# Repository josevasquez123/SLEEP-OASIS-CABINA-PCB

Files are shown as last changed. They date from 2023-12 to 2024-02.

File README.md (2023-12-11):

# WNR-CABINA-PCB
Domotic control of LED lights with CAN connection. 

## Topology
imagen
Motherboard has internet connection to receive commands by MQTT and then, send instruction by CAN to the boards inside the rooms. The present board is the one that will be placed inside the room.

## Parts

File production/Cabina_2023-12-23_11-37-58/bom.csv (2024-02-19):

Designator | Footprint | Quantity | Value | LCSC Part #
C102 | C_Elec_10x10.2 | 1 | 330u | C239324
C103 | CP_Elec_10x10.5 | 1 | 220u | C2886113
C104, C105 | 0805 | 2 | 10u | C15850
C300 | 0603 | 1 | 10u | C19702
C301, C302, C303, C304, C308, C311, C312 | 0402 | 7 | 100n | C1525
C305 | 0402 | 1 | 10n | C15195
C306, C307 | 0603 | 2 | 1u | C15849
C309, C310 | 0402 | 2 | 10p | C32949
D100, D201, D205, D209, D212 | SOD_123FL | 5 | SMF24A-TP | C545276
D101 | D_SOD-123 | 1 | MMSZ4697T1G | C48870
D102 | D_SMA | 1 | ss34 | C8678
D103 | 0603 | 1 | GREEN | C72043
D200, D204, D208, D213 | D_SOD-128 | 4 | PROTECCION | C513108
D202, D206, D210, D214 | SOD_123FL | 4 | SM4007PL | C64898
D203 | 0603 | 1 | LED_HEADBOARD | C72038
D207, D211, D215 | 0603 | 3 | LED_TABLE | C72038
H1, H2, H3, H4 | MountingHole_3.2mm_M3 | 4 | MountingHole
J100 | PhoenixContact_MSTBA_2,5_2-G-5,08_1x02_P5.08mm_Horizontal | 1 | VCC INPUT
J101 | JST_B2B-XH-A_LF__SN_ | 1 | SWITCH ON/OFF
J103 | PinHeader_1x02_P2.54mm_Vertical | 1 | FAN VOLTAGE
J200, J201, J202 | PhoenixContact_MSTBA_2,5_5-G-5,08_1x05_P5.08mm_Horizontal | 3 | LIGHT SWITCH & LED STRIP
J203 | PhoenixContact_MSTBA_2,5_2-G-5,08_1x02_P5.08mm_Horizontal | 1 | LED STRIP
J300 | PinSocket_1x03_P2.54mm_Vertical | 1 | Serial Wire Debug
J301 | SW_DIP_SPSTx05_Slide_9.78x14.88mm_W7.62mm_P2.54mm | 1 | CAN_ID_CONFIG
J302 | PhoenixContact_MSTBA_2,5_2-G-5,08_1x02_P5.08mm_Horizontal | 1 | CAN_INPUT
J304 | PinHeader_1x02_P2.54mm_Vertical | 1 | JUMPER_CANL
K200 | Relay_SPDT_Finder_36.11 | 1 | RELAY_HEADBOARD
K201 | Relay_SPDT_Finder_36.11 | 1 | RELAY_TABLE
K202 | Relay_SPDT_Finder_36.11 | 1 | RELAY_CEILING
K203 | Relay_SPDT_Finder_36.11 | 1 | RELAY_SIGN
L101 | SMD_12.3X12.3mm | 1 | 68u | C2929504
L300 | 0603 | 1 | 10n | C913709
Q100 | SOT-23 | 1 | WST4045 | C719073
Q200, Q201, Q202, Q203 | SOT-23 | 4 | MMBT3904 | C20526
R100 | 1206 | 1 | 100K | C17900
R101, R200, R201, R203, R204, R206, R207, R209, R210 | 0603 | 9 | 1k | C21190
R202, R205, R208, R211 | 0603 | 4 | 10K | C25804
R300 | 0402 | 1 | 10k | C25744
R301, R303, R305 | 0805 | 3 | 33k | C17633
R302, R304, R306 | 0805 | 3 | 5.1k | C27834
R308 | 0805 | 1 | 120 | C17437
S300 | SWITCH_SMD | 1 | TS-1187A-B-A-B | C318884
TP100, TP101, TP102, TP103, TP104, TP300, TP301, TP302, TP303, TP304, TP307, TP308 | TestPoint_Pad_D2.0mm | 12 | TestPoint
U100 | TO-263-5_TabPin3 | 1 | LM2596S-5 | C10002
U101 | SOT-223-3_TabPin2 | 1 | AMS1117-3.3 | C6186
U300 | LQFP-48_7x7mm_P0.5mm | 1 | STM32F103C8Tx | C8734
U301 | SOIC-8_3.9x4.9mm_P1.27mm | 1 | MCP2562-E-SN | C191417
Y300 | Crystal_SMD_3225-4Pin_3.2x2.5mm | 1 | 16MHz | C13738

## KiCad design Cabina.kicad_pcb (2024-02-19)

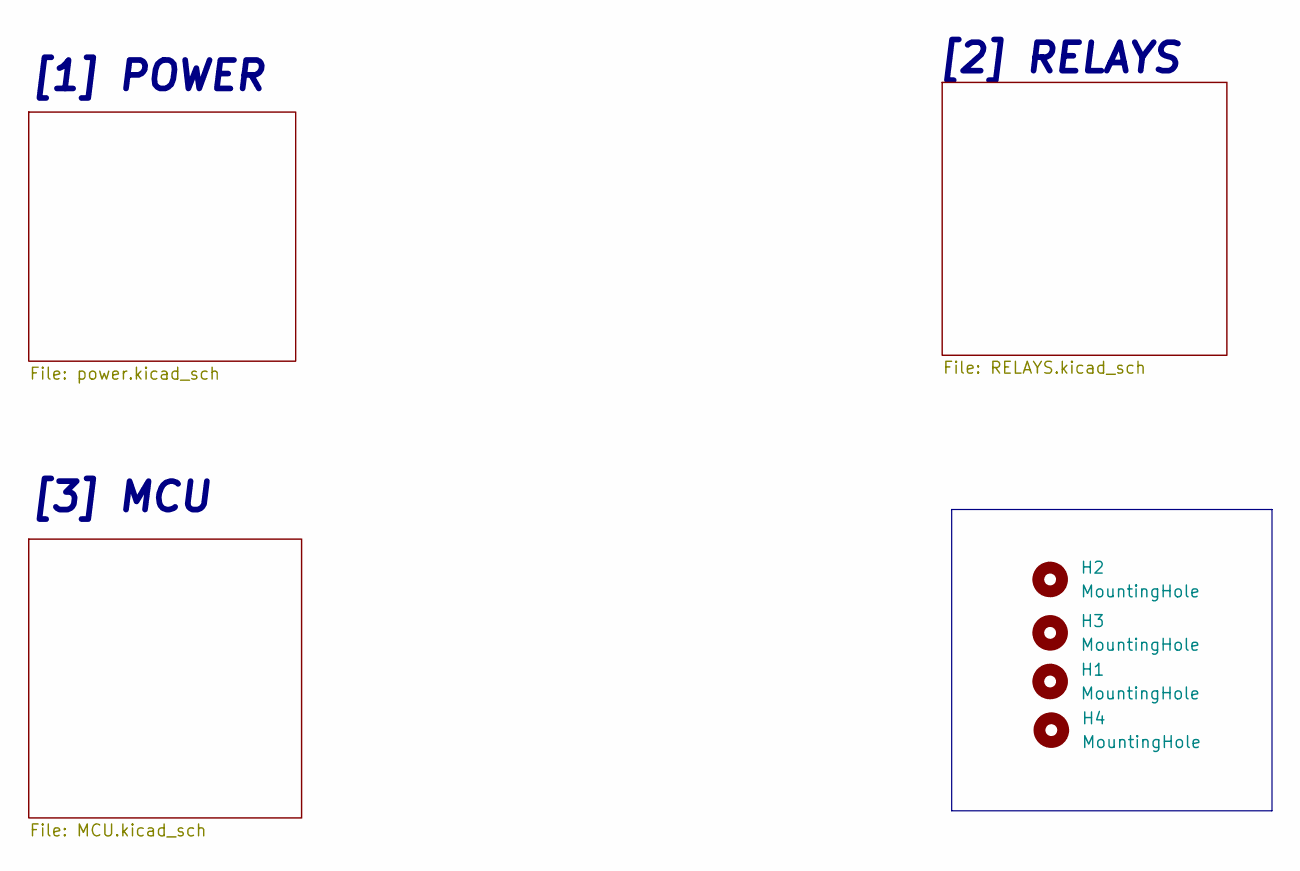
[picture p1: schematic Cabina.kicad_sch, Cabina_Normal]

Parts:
H1, H2, H3, H4: MountingHole; MountingHole_3.2mm_M3

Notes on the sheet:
[1] POWER
[2] RELAYS
[3] MCU

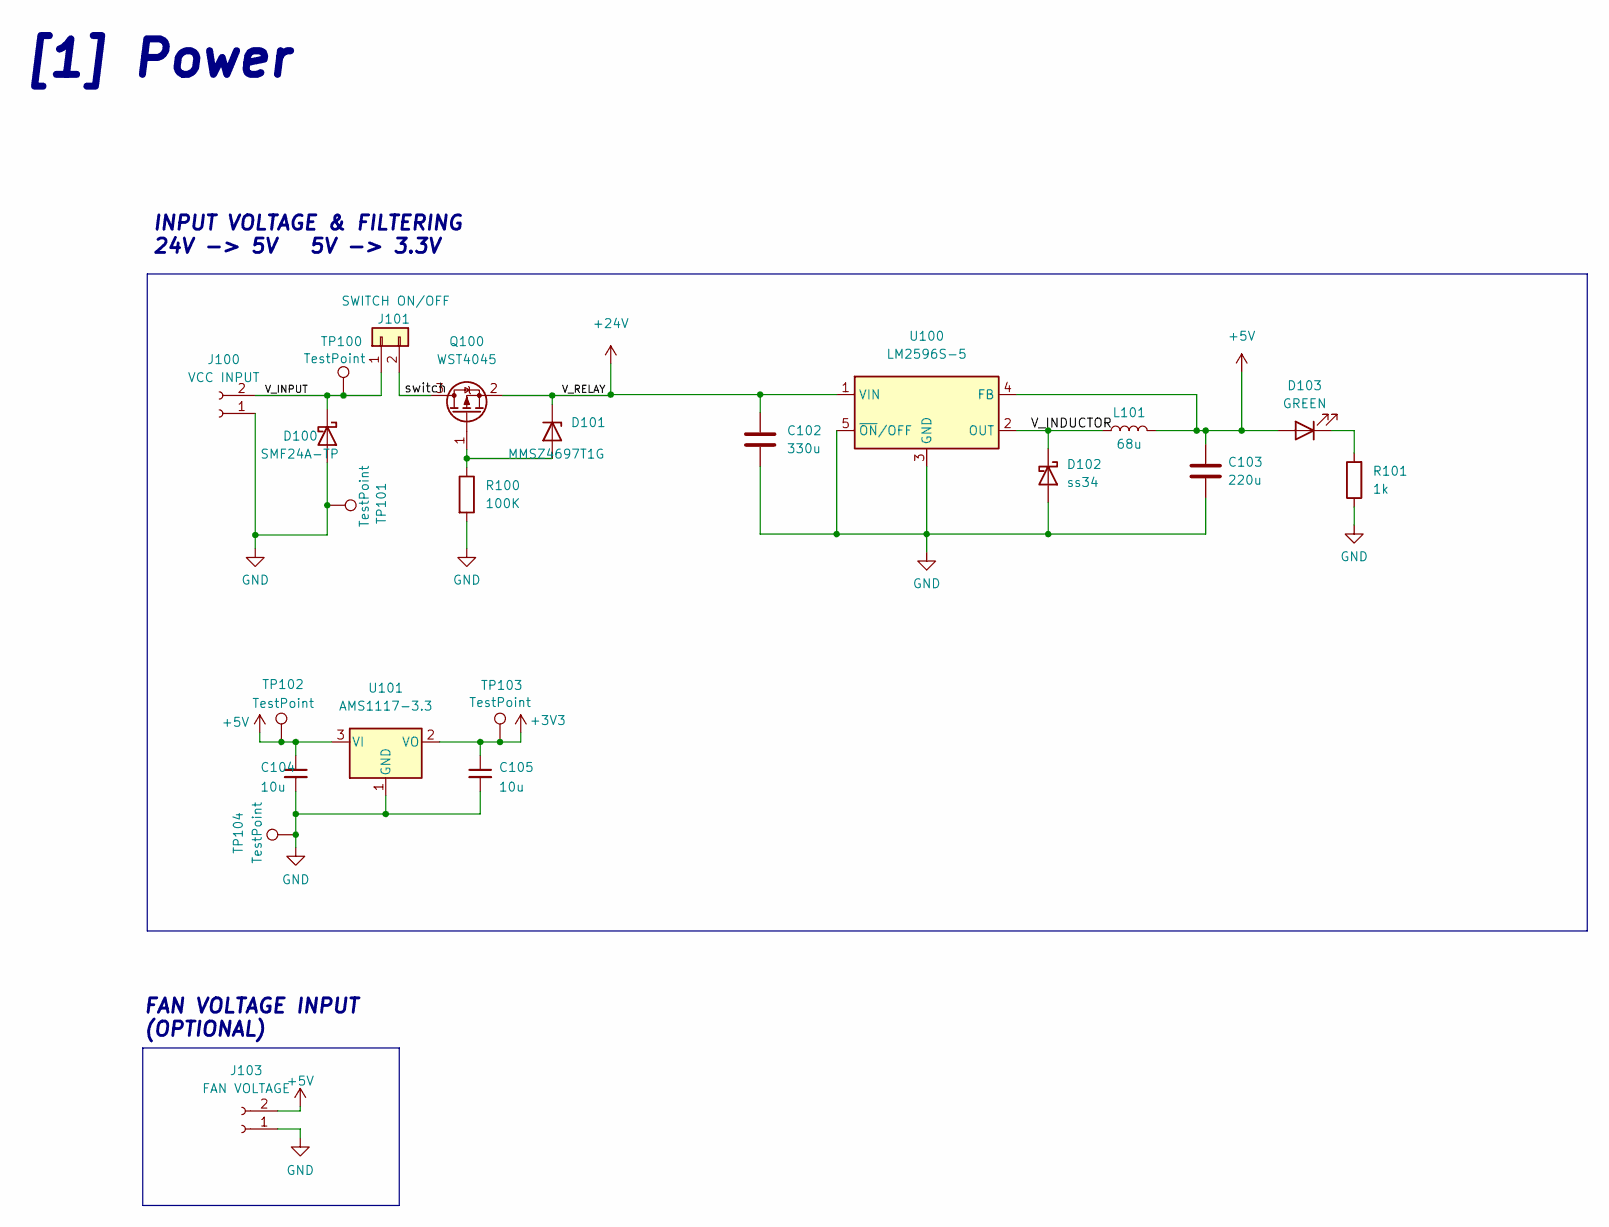
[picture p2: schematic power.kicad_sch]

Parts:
C102: 330u; C_Elec_10x10.2; LCSC C239324
C103: 220u; CP_Elec_10x10.5; LCSC C2886113
C104, C105: 10u; C_0805_2012Metric; LCSC C15850
D100: SMF24A-TP; SOD_123FL; LCSC C545276
D101: MMSZ4697T1G; D_SOD-123; LCSC C48870
D102: ss34; D_SMA; LCSC C8678
D103: GREEN; LED_0603_1608Metric; LCSC C72038
J100: VCC INPUT; PhoenixContact_MSTBA_2,5_2-G-5,08_1x02_P5.08mm_Horizontal
J101: SWITCH ON/OFF; JST_B2B-XH-A_LF__SN_
J103: FAN VOLTAGE; PinHeader_1x02_P2.54mm_Vertical
L101: 68u; SMD_12.3X12.3mm; LCSC C2929504
Q100: WST4045; SOT-23; LCSC C719073
R100: 100K; R_1206_3216Metric; LCSC C17900
R101: 1k; R_0603_1608Metric; LCSC C21190
TP100, TP101, TP102, TP103, TP104: TestPoint; TestPoint_Pad_D2.0mm
U100: LM2596S-5; TO-263-5_TabPin3; LCSC C10002
U101: AMS1117-3.3; SOT-223-3_TabPin2; LCSC C6186

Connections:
+3V3: C105.1, TP103.1, U101.2 (VO); also elsewhere on the board
+5V: C103.1, C104.1, D103.2 (A), J103.2, L101.2, TP102.1, U100.4 (FB), U101.3 (VI); also elsewhere on the board
+24V: C102.1, D101.1 (K), Q100.2 (S), U100.1 (VIN); also elsewhere on the board
/POWER/V_INDUCTOR: D102.1 (K), L101.1, U100.2 (OUT)
/POWER/V_INPUT: D100.1 (K), J100.2, J101.1, TP100.1
/POWER/switch: J101.2, Q100.3 (D)
GND: C102.2, C103.2, C104.2, C105.2, D100.2 (A), D102.2 (A), J100.1, J103.1, R100.2, R101.1, TP101.1, TP104.1, U100.3 (GND), U100.5 (~ON/OFF), U101.1 (GND); also elsewhere on the board
unnamed: D101.2 (A), Q100.1 (G), R100.1
unnamed: D103.1 (K), R101.2

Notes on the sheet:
[1] Power
INPUT VOLTAGE & FILTERING 24V -> 5V 5V -> 3.3V
FAN VOLTAGE INPUT (OPTIONAL)

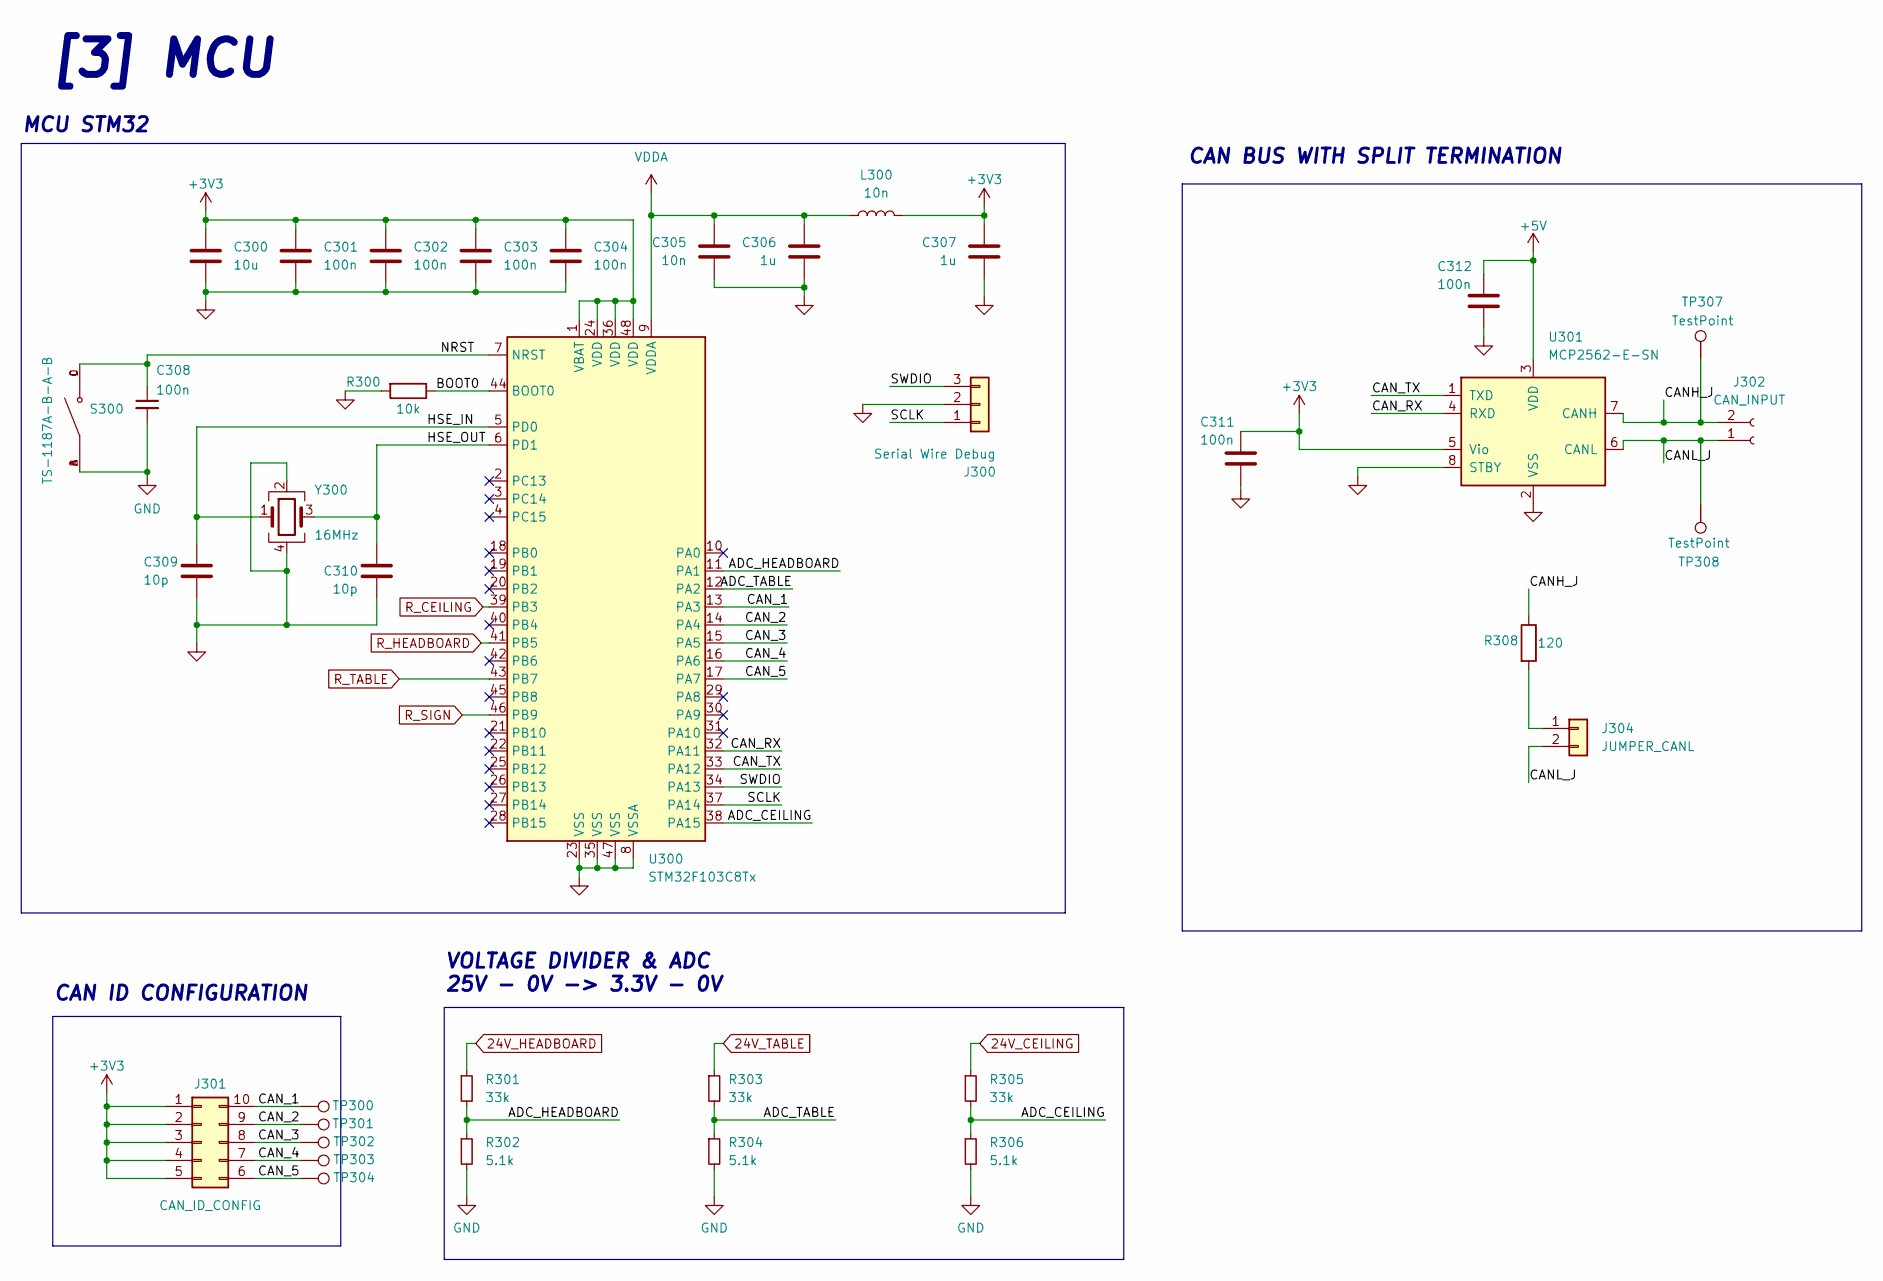
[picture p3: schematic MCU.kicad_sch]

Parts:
C300: 10u; C_0603_1608Metric; LCSC C19702
C301, C302, C303, C304, C308, C311, C312: 100n; C_0402_1005Metric; LCSC C1525
C305: 10n; C_0402_1005Metric; LCSC C15195
C306, C307: 1u; C_0603_1608Metric; LCSC C15849
C309, C310: 10p; C_0402_1005Metric; LCSC C32949
J300: Serial Wire Debug; PinSocket_1x03_P2.54mm_Vertical
J301: CAN_ID_CONFIG; SW_DIP_SPSTx05_Slide_9.78x14.88mm_W7.62mm_P2.54mm
J302: CAN_INPUT; PhoenixContact_MSTBA_2,5_2-G-5,08_1x02_P5.08mm_Horizontal
J304: JUMPER_CANL; PinHeader_1x02_P2.54mm_Vertical
L300: 10n; L_0603_1608Metric; LCSC C913709
R300: 10k; R_0402_1005Metric; LCSC C25744
R301, R303, R305: 33k; R_0805_2012Metric; LCSC C17633
R302, R304, R306: 5.1k; R_0805_2012Metric; LCSC C27834
R308: 120; R_0805_2012Metric; LCSC C17437
S300: TS-1187A-B-A-B; SWITCH_SMD; LCSC C318884
TP300, TP301, TP302, TP303, TP304, TP307, TP308: TestPoint; TestPoint_Pad_D2.0mm
U300: STM32F103C8Tx; LQFP-48_7x7mm_P0.5mm; LCSC C8734
U301: MCP2562-E-SN; SOIC-8_3.9x4.9mm_P1.27mm; LCSC C191417
Y300: 16MHz; Crystal_SMD_3225-4Pin_3.2x2.5mm; LCSC C13738

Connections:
24V_CEILING: R305.1; also elsewhere on the board
24V_HEADBOARD: R301.1; also elsewhere on the board
24V_TABLE: R303.1; also elsewhere on the board
+3V3: C300.1, C301.1, C302.1, C303.1, C304.1, C307.1, C311.1, J301.1, J301.2, J301.3, J301.4, J301.5, L300.2, U300.1 (VBAT), U300.24 (VDD), U300.36 (VDD), U300.48 (VDD), U301.5 (Vio); also elsewhere on the board
+5V: C312.1, U301.3 (VDD); also elsewhere on the board
/MCU/ADC_CEILING: R305.2, R306.1, U300.38 (PA15)
/MCU/ADC_HEADBOARD: R301.2, R302.1, U300.11 (PA1)
/MCU/ADC_TABLE: R303.2, R304.1, U300.12 (PA2)
/MCU/BOOT0: R300.1, U300.44 (BOOT0)
/MCU/CANH_J: J302.2, R308.1, TP307.1, U301.7 (CANH)
/MCU/CANL_J: J302.1, J304.2, TP308.1, U301.6 (CANL)
/MCU/CAN_1: J301.10, TP300.1, U300.13 (PA3)
/MCU/CAN_2: J301.9, TP301.1, U300.14 (PA4)
/MCU/CAN_3: J301.8, TP302.1, U300.15 (PA5)
/MCU/CAN_4: J301.7, TP303.1, U300.16 (PA6)
/MCU/CAN_5: J301.6, TP304.1, U300.17 (PA7)
/MCU/CAN_RX: U300.32 (PA11), U301.4 (RXD)
/MCU/CAN_TX: U300.33 (PA12), U301.1 (TXD)
/MCU/HSE_IN: C309.1, U300.5 (PD0), Y300.1
/MCU/HSE_OUT: C310.1, U300.6 (PD1), Y300.3
/MCU/NRST: C308.1, S300.C, S300.D, U300.7 (NRST)
/MCU/SCLK: J300.1, U300.37 (PA14)
/MCU/SWDIO: J300.3, U300.34 (PA13)
GND: C300.2, C301.2, C302.2, C303.2, C304.2, C305.2, C306.2, C307.2, C308.2, C309.2, C310.2, C311.2, C312.2, J300.2, R300.2, R302.2, R304.2, R306.2, S300.A, S300.B, U300.8 (VSSA), U300.23 (VSS), U300.35 (VSS), U300.47 (VSS), U301.2 (VSS), U301.8 (STBY), Y300.2, Y300.4; also elsewhere on the board
unnamed: J304.1, R308.2
R_CEILING: U300.39 (PB3); also elsewhere on the board
R_HEADBOARD: U300.41 (PB5); also elsewhere on the board
R_SIGN: U300.46 (PB9); also elsewhere on the board
R_TABLE: U300.43 (PB7); also elsewhere on the board
VDDA: C305.1, C306.1, L300.1, U300.9 (VDDA)

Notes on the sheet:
CAN ID CONFIGURATION
VOLTAGE DIVIDER & ADC 25V - 0V -> 3.3V - 0V
CAN BUS WITH SPLIT TERMINATION
[3] MCU
MCU STM32

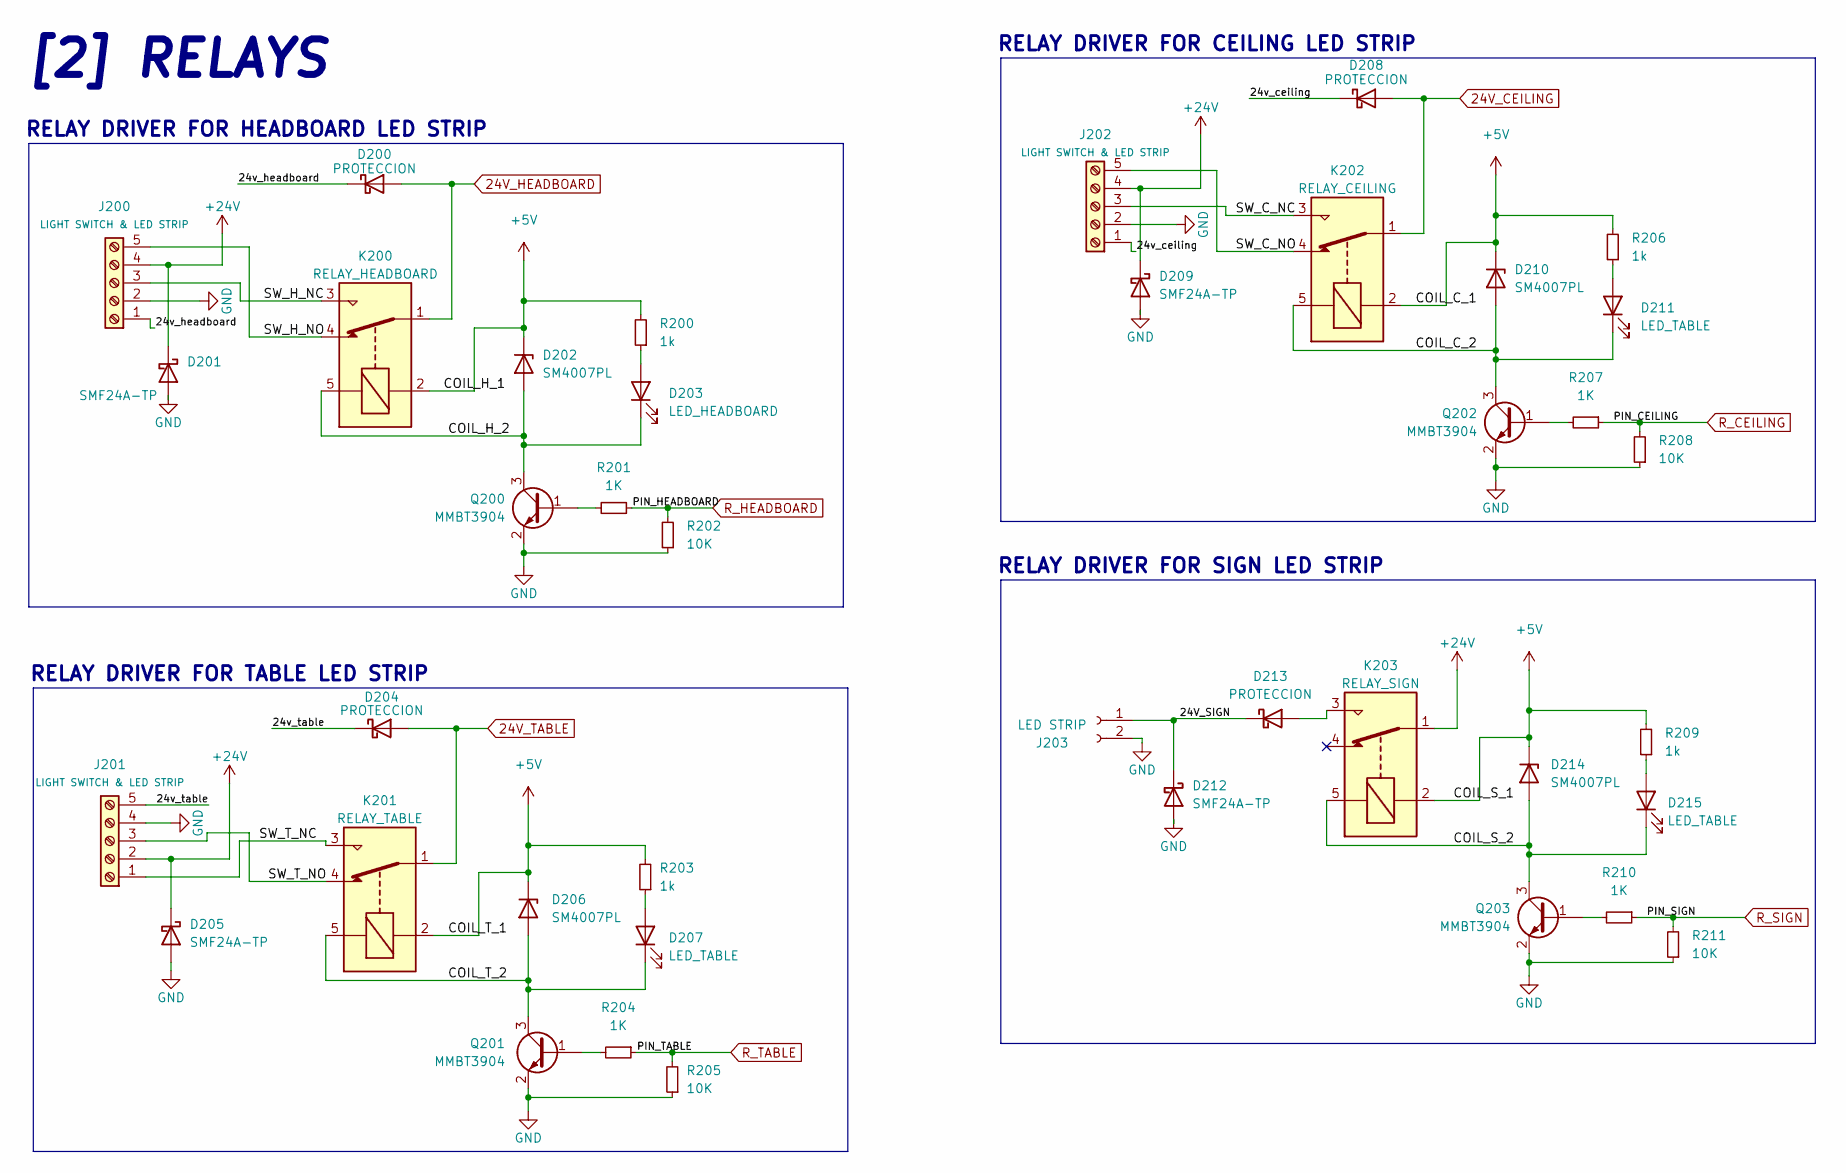
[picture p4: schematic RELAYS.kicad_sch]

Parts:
D200, D204, D208, D213: PROTECCION; Nexperia_CFP3_SOD-123W; LCSC C552879
D201, D205, D209, D212: SMF24A-TP; SOD_123FL; LCSC C545276
D202, D206, D210, D214: SM4007PL; SOD_123FL; LCSC C64898
D203: LED_HEADBOARD; LED_0603_1608Metric; LCSC C72038
D207, D211, D215: LED_TABLE; LED_0603_1608Metric; LCSC C72038
J200, J201, J202: LIGHT SWITCH & LED STRIP; PhoenixContact_MSTBA_2,5_5-G-5,08_1x05_P5.08mm_Horizontal
J203: LED STRIP; PhoenixContact_MSTBA_2,5_2-G-5,08_1x02_P5.08mm_Horizontal
K200: RELAY_HEADBOARD; Relay_SPDT_Finder_36.11
K201: RELAY_TABLE; Relay_SPDT_Finder_36.11
K202: RELAY_CEILING; Relay_SPDT_Finder_36.11
K203: RELAY_SIGN; Relay_SPDT_Finder_36.11
Q200, Q201, Q202, Q203: MMBT3904; SOT-23; LCSC C20526
R200, R203, R206, R209: 1k; R_0603_1608Metric; LCSC C21190
R201, R204, R207, R210: 1K; R_0603_1608Metric; LCSC C21190
R202, R205, R208, R211: 10K; R_0603_1608Metric; LCSC C25804

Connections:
24V_CEILING: D208.2 (A), K202.1; also elsewhere on the board
24V_HEADBOARD: D200.2 (A), K200.1; also elsewhere on the board
24V_TABLE: D204.2 (A), K201.1; also elsewhere on the board
+5V: D202.1 (K), D206.1 (K), D210.1 (K), D214.1 (K), K200.2, K201.2, K202.2, K203.2, R200.2, R203.2, R206.2, R209.2; also elsewhere on the board
+24V: D201.1 (K), D205.1 (K), D209.1 (K), J200.4, J201.2, J202.4, K203.1; also elsewhere on the board
/RELAYS/24V_SIGN: D212.1 (K), D213.1 (K), J203.1
/RELAYS/24v_ceiling: D208.1 (K), J202.1
/RELAYS/24v_headboard: D200.1 (K), J200.1
/RELAYS/24v_table: D204.1 (K), J201.5
/RELAYS/COIL_C_2: D210.2 (A), D211.1 (K), K202.5, Q202.3 (C)
/RELAYS/COIL_H_2: D202.2 (A), D203.1 (K), K200.5, Q200.3 (C)
/RELAYS/COIL_S_2: D214.2 (A), D215.1 (K), K203.5, Q203.3 (C)
/RELAYS/COIL_T_2: D206.2 (A), D207.1 (K), K201.5, Q201.3 (C)
/RELAYS/SW_C_NC: J202.3, K202.3
/RELAYS/SW_C_NO: J202.5, K202.4
/RELAYS/SW_H_NC: J200.3, K200.3
/RELAYS/SW_H_NO: J200.5, K200.4
/RELAYS/SW_T_NC: J201.1, K201.3
/RELAYS/SW_T_NO: J201.3, K201.4
GND: D201.2 (A), D205.2 (A), D209.2 (A), D212.2 (A), J200.2, J201.4, J202.2, J203.2, Q200.2 (E), Q201.2 (E), Q202.2 (E), Q203.2 (E), R202.1, R205.1, R208.1, R211.1; also elsewhere on the board
unnamed: D203.2 (A), R200.1
unnamed: D207.2 (A), R203.1
unnamed: D211.2 (A), R206.1
unnamed: D213.2 (A), K203.3
unnamed: D215.2 (A), R209.1
unnamed: Q200.1 (B), R201.2
unnamed: Q201.1 (B), R204.2
unnamed: Q202.1 (B), R207.2
unnamed: Q203.1 (B), R210.2
R_CEILING: R207.1, R208.2; also elsewhere on the board
R_HEADBOARD: R201.1, R202.2; also elsewhere on the board
R_SIGN: R210.1, R211.2; also elsewhere on the board
R_TABLE: R204.1, R205.2; also elsewhere on the board

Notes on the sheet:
RELAY DRIVER FOR HEADBOARD LED STRIP
RELAY DRIVER FOR TABLE LED STRIP
[2] RELAYS
RELAY DRIVER FOR CEILING LED STRIP
RELAY DRIVER FOR SIGN LED STRIP

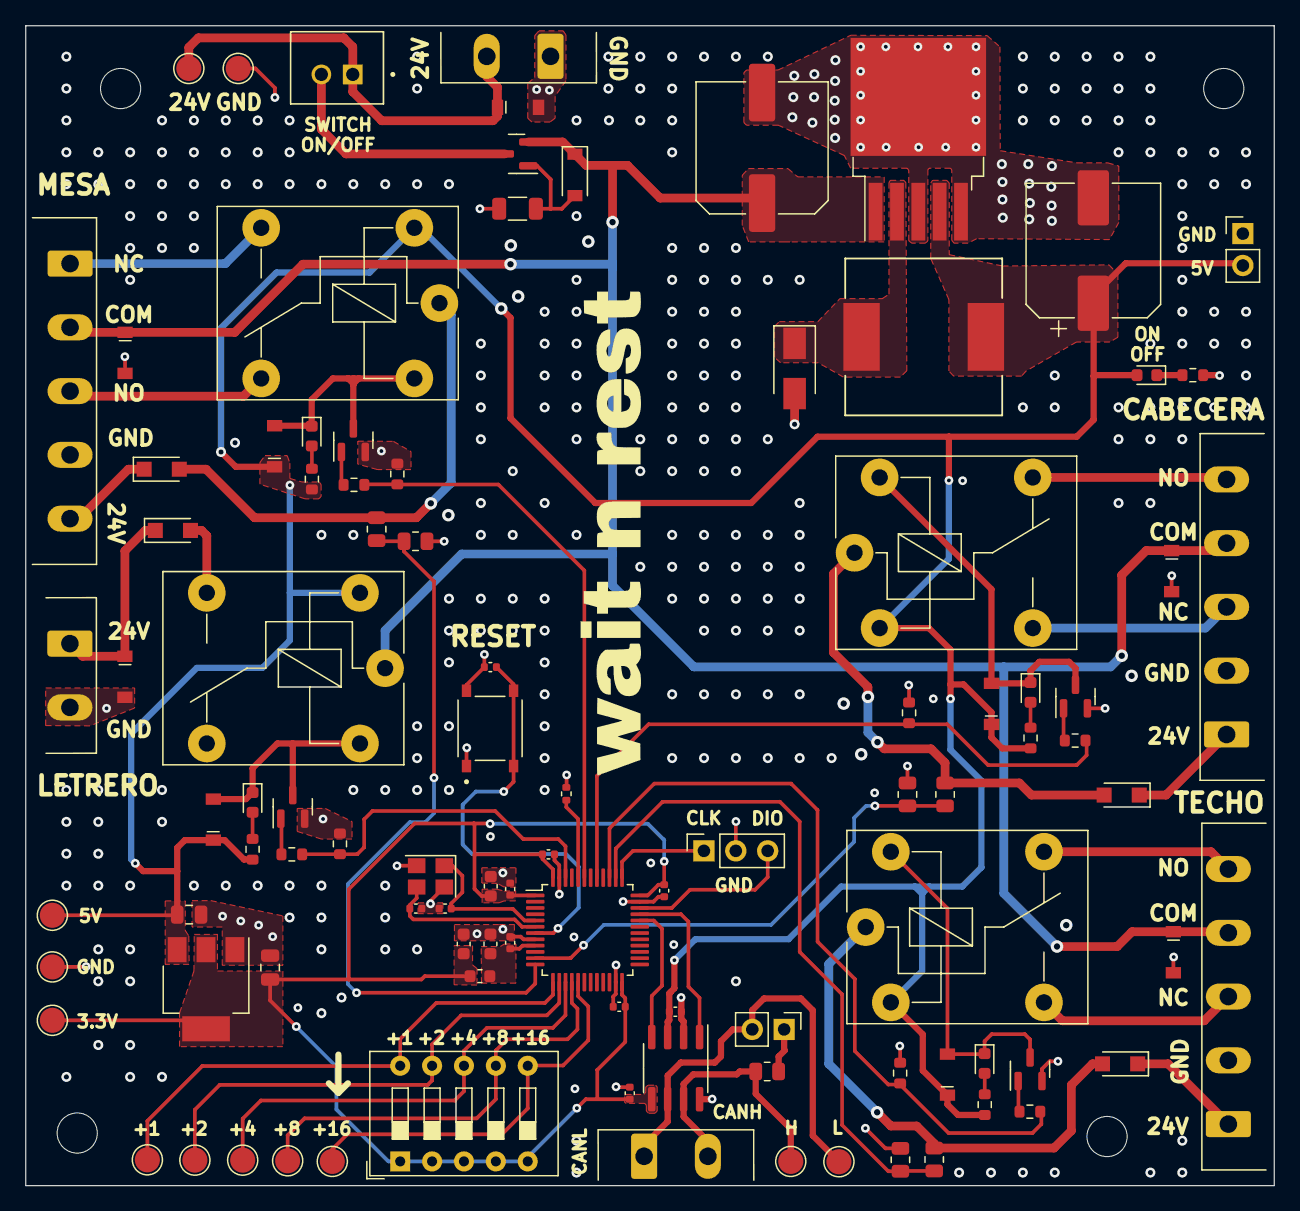
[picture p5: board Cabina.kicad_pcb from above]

Board: 4 copper layers, 99.5 x 92.4 mm, 103 parts (0 on the bottom side), 59 nets.

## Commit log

2023-12-20 change board stackup
    [Cabina-B_Cu.gbl, Cabina-B_Mask.gbs, Cabina-B_Paste.gbp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]
2024-02-19 version validada
    [Cabina.kicad_pcb, RELAYS.kicad_sch, bom.csv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]
